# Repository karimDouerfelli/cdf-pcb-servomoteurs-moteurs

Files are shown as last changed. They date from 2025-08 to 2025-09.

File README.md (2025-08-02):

# 🛠️ PCB Servomoteurs & Moteurs – Coupe de France de Robotique 2026



Ce projet est un PCB dédié au pilotage de **moteurs** et **servomoteurs**, conçu pour la **Coupe de France de Robotique 2026**.

## ⚙️ Fonctionnalités principales

- Contrôle de servomoteurs via :
  - **UART**
  - **PWM**
- Carte en **4 couches** avec une **couche Power** divisée en 3 zones.

---

## 🧩 Schéma

### Schéma global :
Schéma global

### STM32 et ses compléments :
STM32

### Régulateurs :
Régulateurs

---

## 🧱 Empreintes

Empreinte 1  
Empreinte 2  
Empreinte 3  
Empreinte 4

---

## 🧵 Routage

### Placement des composants :
Placement

---

## 🧭 Couches PCB

- **GND Layer** :  
  GND

- **Top Layer (Rouge)** :  
  Top

- **Bottom Layer (Bleue)** :  
  Bottom

- **Power Layer** :  
  Power

---

## 📏 Dimensionnement des pistes

Nous avons utilisé la formule suivante pour calculer la largeur des pistes selon le courant attendu :

Formule  
Référence

---

## 🙏 Remerciements

Merci à **@CaptainJaja** pour son aide sur le projet ❤️  
CaptainJaja

---

## 💬 Retours bienvenus

N'hésitez pas à **ouvrir une issue** ou **créer une pull request** si vous avez des remarques ou des suggestions.

---

---

# 🛠️ PCB for Servomotors & Motors – French Robotics Cup 2026



This project is a PCB designed to control **motors** and especially **servomotors**, built for the **French Robotics Cup 2026**.

## ⚙️ Key Features

- Supports two control modes for servos:
  - **UART**
  - **PWM**
- Built on a **4-layer board** with a **Power layer** split into 3 zones.

---

## 🧩 Schematics

### Global schematic:
Schematic

### STM32 and peripherals:
STM32

### Voltage regulators:
Regulators

---

## 🧱 Footprints

Footprint 1  
Footprint 2  
Footprint 3  
Footprint 4

---

## 🧵 Routing

### Component placement:
Placement

---

## 🧭 PCB Layers

- **GND Layer**  
  GND

- **Top Layer (Red)**  
  Top

- **Bottom Layer (Blue)**  
  Bottom

- **Power Layer**  
  Power

---

## 📏 Trace Sizing

Trace widths were calculated using the following formula based on expected current:

Formula  
Reference

---

## 🙏 Acknowledgments

Big thanks to **@CaptainJaja** for contributions ❤️  
CaptainJaja

---

## 💬 Feedback

Feel free to **open an issue** or **submit a pull request** if you have ideas or improvements to suggest.

---

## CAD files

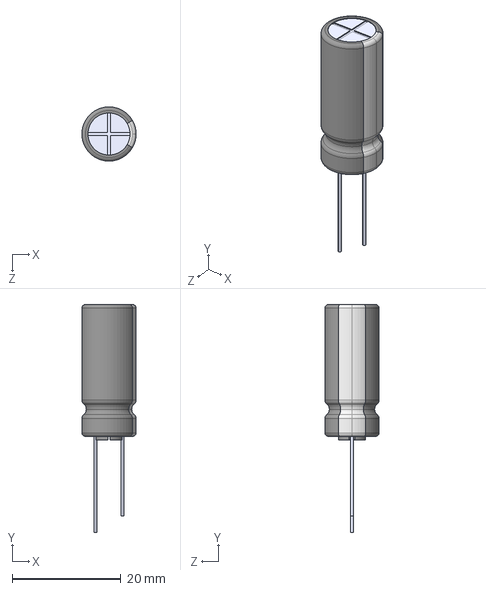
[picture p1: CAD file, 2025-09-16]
pcbservo-dc/EEUFS1K221LB/EEUFS1K221LB.step
10.0 x 42.0 x 9.99 mm

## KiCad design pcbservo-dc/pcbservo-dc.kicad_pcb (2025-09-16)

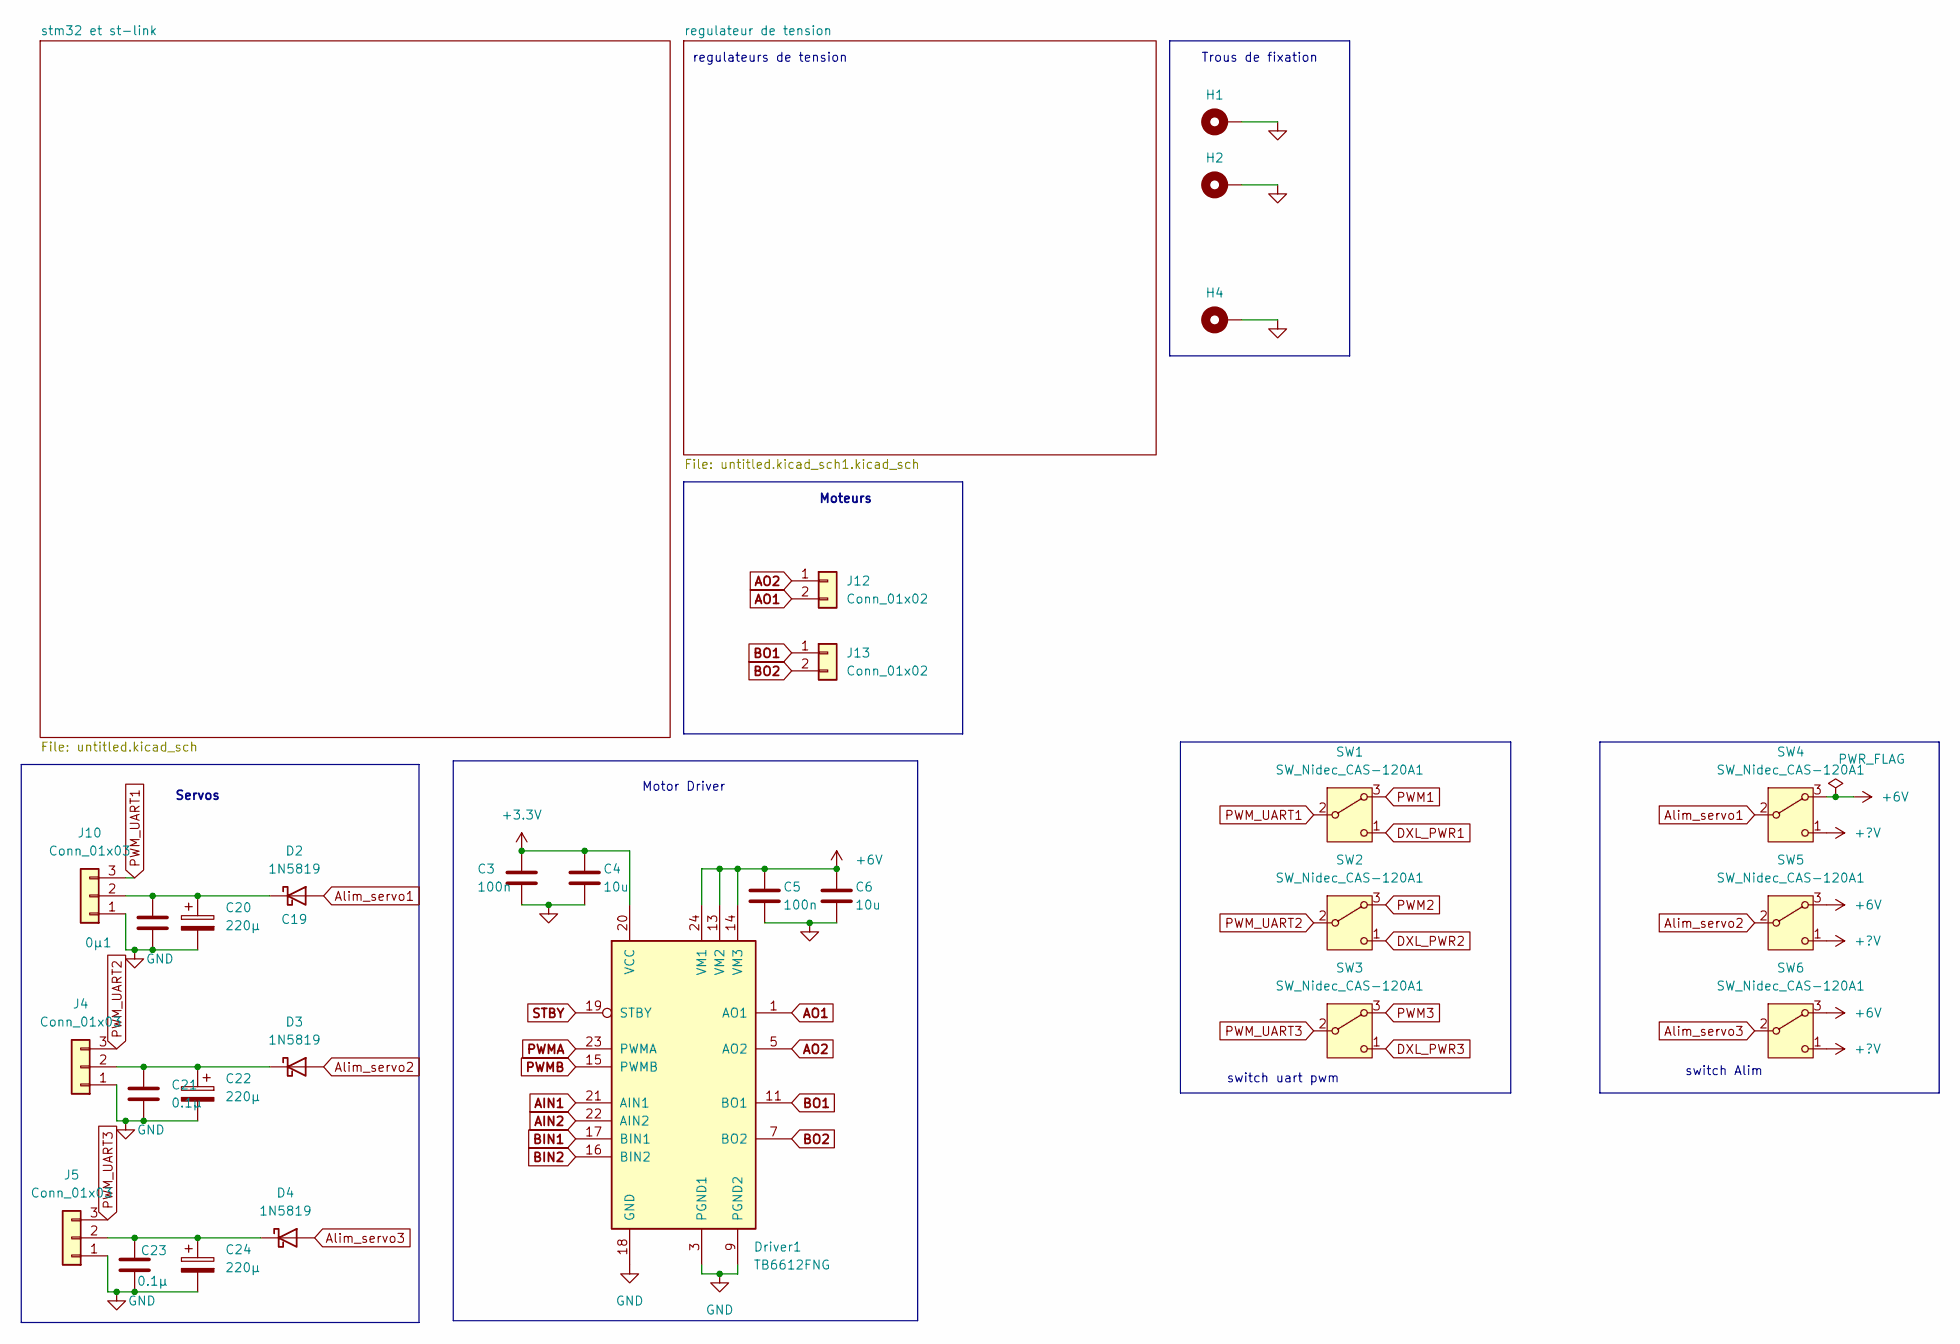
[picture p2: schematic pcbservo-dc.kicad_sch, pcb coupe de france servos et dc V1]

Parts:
C3, C5: 100n; C_0402_1005Metric
C4, C6: 10u; C_0805_2012Metric
C19: 0µ1; C_0805_2012Metric
C20, C22, C24: 220µ; CAPPRD500W60D1000H2500
C21, C23: 0.1µ; C_0805_2012Metric
D2, D3, D4: 1N5819; D_SOD-123
Driver1: TB6612FNG; SSOP-24_5.3x8.2mm_P0.65mm
H1, H2, H4: MountingHole_Pad; MountingHole_2.7mm_M2.5_Pad
J4, J5, J10: Conn_01x03; JST_EH_B3B-EH-A_1x03_P2.50mm_Vertical
J12, J13: Conn_01x02; JST_EH_B2B-EH-A_1x02_P2.50mm_Vertical
SW1, SW2, SW3, SW4, SW5, SW6: SW_Nidec_CAS-120A1; Nidec_Copal_CAS-120A

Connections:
+3.3V: C3.1, C4.1, Driver1.20 (VCC); also elsewhere on the board
+6V: C5.1, C6.1, Driver1.13 (VM2), Driver1.14 (VM3), Driver1.24 (VM1), SW4.3 (A), SW5.3 (A), SW6.3 (A); also elsewhere on the board
+?V: SW4.1 (C), SW5.1 (C), SW6.1 (C); also elsewhere on the board
AIN1: Driver1.21 (AIN1); also elsewhere on the board
AIN2: Driver1.22 (AIN2); also elsewhere on the board
AO1: Driver1.1 (AO1), Driver1.2 (AO1), J12.2
AO2: Driver1.5 (AO2), Driver1.6 (AO2), J12.1
Alim_servo1: D2.2 (A), SW4.2 (B)
Alim_servo2: D3.2 (A), SW5.2 (B)
Alim_servo3: D4.2 (A), SW6.2 (B)
BIN1: Driver1.17 (BIN1); also elsewhere on the board
BIN2: Driver1.16 (BIN2); also elsewhere on the board
BO1: Driver1.11 (BO1), Driver1.12 (BO1), J13.1
BO2: Driver1.7 (BO2), Driver1.8 (BO2), J13.2
DXL_PWR1: SW1.1 (C); also elsewhere on the board
DXL_PWR2: SW2.1 (C); also elsewhere on the board
DXL_PWR3: SW3.1 (C); also elsewhere on the board
GND: C3.2, C4.2, C5.2, C6.2, C19.2, C20.2, C21.2, C22.2, C23.2, C24.2, Driver1.3 (PGND1), Driver1.4 (PGND1), Driver1.9 (PGND2), Driver1.10 (PGND2), Driver1.18 (GND), H1.1, H2.1, H4.1, J4.1, J5.1, J10.1; also elsewhere on the board
unnamed: C19.1, C20.1, D2.1 (K), J10.2
unnamed: C21.1, C22.1, D3.1 (K), J4.2
unnamed: C23.1, C24.1, D4.1 (K), J5.2
PWM1: SW1.3 (A); also elsewhere on the board
PWM2: SW2.3 (A); also elsewhere on the board
PWM3: SW3.3 (A); also elsewhere on the board
PWMA: Driver1.23 (PWMA); also elsewhere on the board
PWMB: Driver1.15 (PWMB); also elsewhere on the board
PWM_UART1: J10.3, SW1.2 (B)
PWM_UART2: J4.3, SW2.2 (B)
PWM_UART3: J5.3, SW3.2 (B)
STBY: Driver1.19 (STBY); also elsewhere on the board

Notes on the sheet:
Trous de fixation
switch uart pwm
Servos
switch Alim
regulateurs de tension
Moteurs
Motor Driver

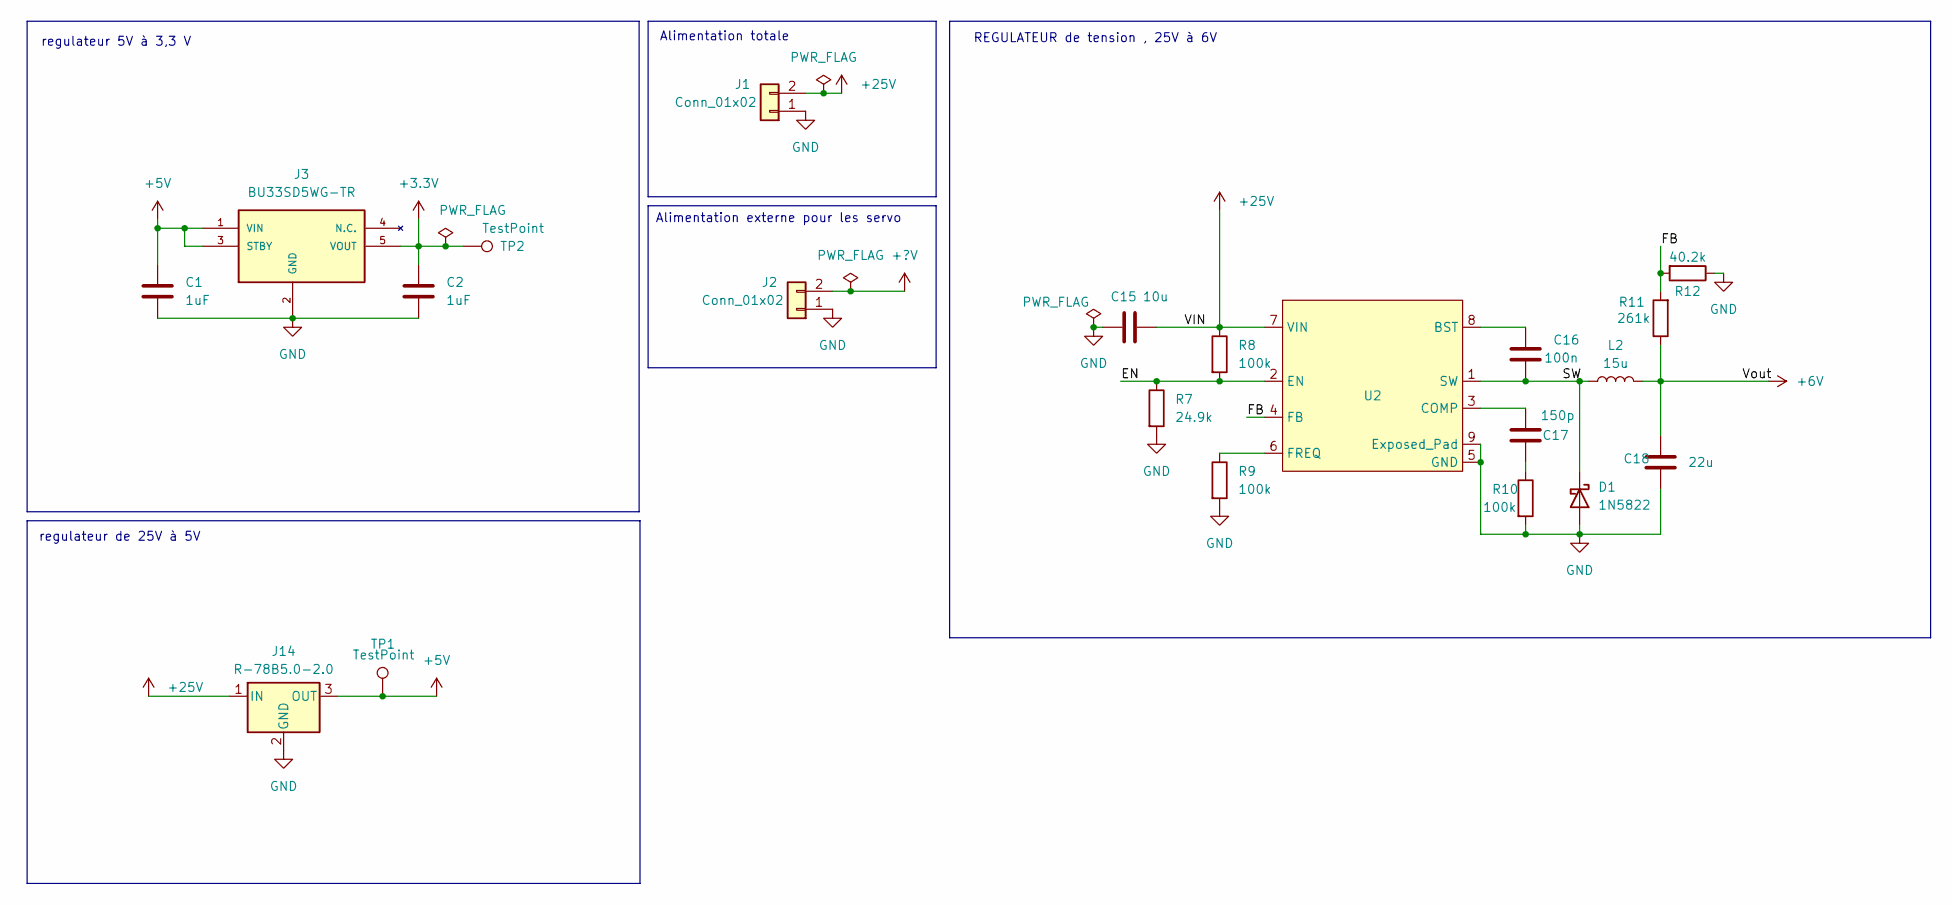
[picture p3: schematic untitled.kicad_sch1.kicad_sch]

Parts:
C1, C2: 1uF; C_0603_1608Metric_Pad1.08x0.95mm_HandSolder
C15: 10u; C_0603_1608Metric
C16: 100n; C_0603_1608Metric
C17: 150p; C_0603_1608Metric
C18: 22u; C_0805_2012Metric
D1: 1N5822; D_SMB
J1, J2: Conn_01x02; JST_EH_B2B-EH-A_1x02_P2.50mm_Vertical
J3: BU33SD5WG-TR; SOT-23-5; Mouser_Part_Number 755-BU33SD5WG-TR
J14: R-78B5.0-2.0; Converter_DCDC_RECOM_R-78B-2.0_THT
L2: 15u; L_12x12mm_H4.5mm
R7: 24.9k; R_0603_1608Metric
R8, R9, R10: 100k; R_0603_1608Metric
R11: 261k; R_0603_1608Metric
R12: 40.2k; R_0603_1608Metric
TP1, TP2: TestPoint; TestPoint_Pad_D1.0mm
U2: MP1584-SOICP8

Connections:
+3.3V: C2.1, J3.5 (VOUT), TP2.1; also elsewhere on the board
+5V: C1.1, J3.1 (VIN), J3.3 (STBY), J14.3 (OUT), TP1.1; also elsewhere on the board
+6V: C18.1, L2.2, R11.1; also elsewhere on the board
+25V: C15.1, J1.2, J14.1 (IN), R8.1, U2.7 (VIN)
+?V: J2.2; also elsewhere on the board
/regulateur de tension/EN: R7.1, R8.2, U2.2 (EN)
/regulateur de tension/FB: R11.2, R12.2, U2.4 (FB)
/regulateur de tension/SW: C16.2, D1.1 (K), L2.1, U2.1 (SW)
GND: C1.2, C2.2, C15.2, C18.2, D1.2 (A), J1.1, J2.1, J3.2 (GND), J14.2 (GND), R7.2, R9.2, R10.2, R12.1, U2.5 (GND), U2.9 (Exposed_Pad); also elsewhere on the board
unnamed: C17.2, R10.1
unnamed: C16.1, U2.8 (BST)
unnamed: C17.1, U2.3 (COMP)
unnamed: R9.1, U2.6 (FREQ)

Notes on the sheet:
regulateur 5V à 3,3 V
Alimentation externe pour les servo
REGULATEUR de tension , 25V à 6V
regulateur de 25V à 5V
Alimentation totale

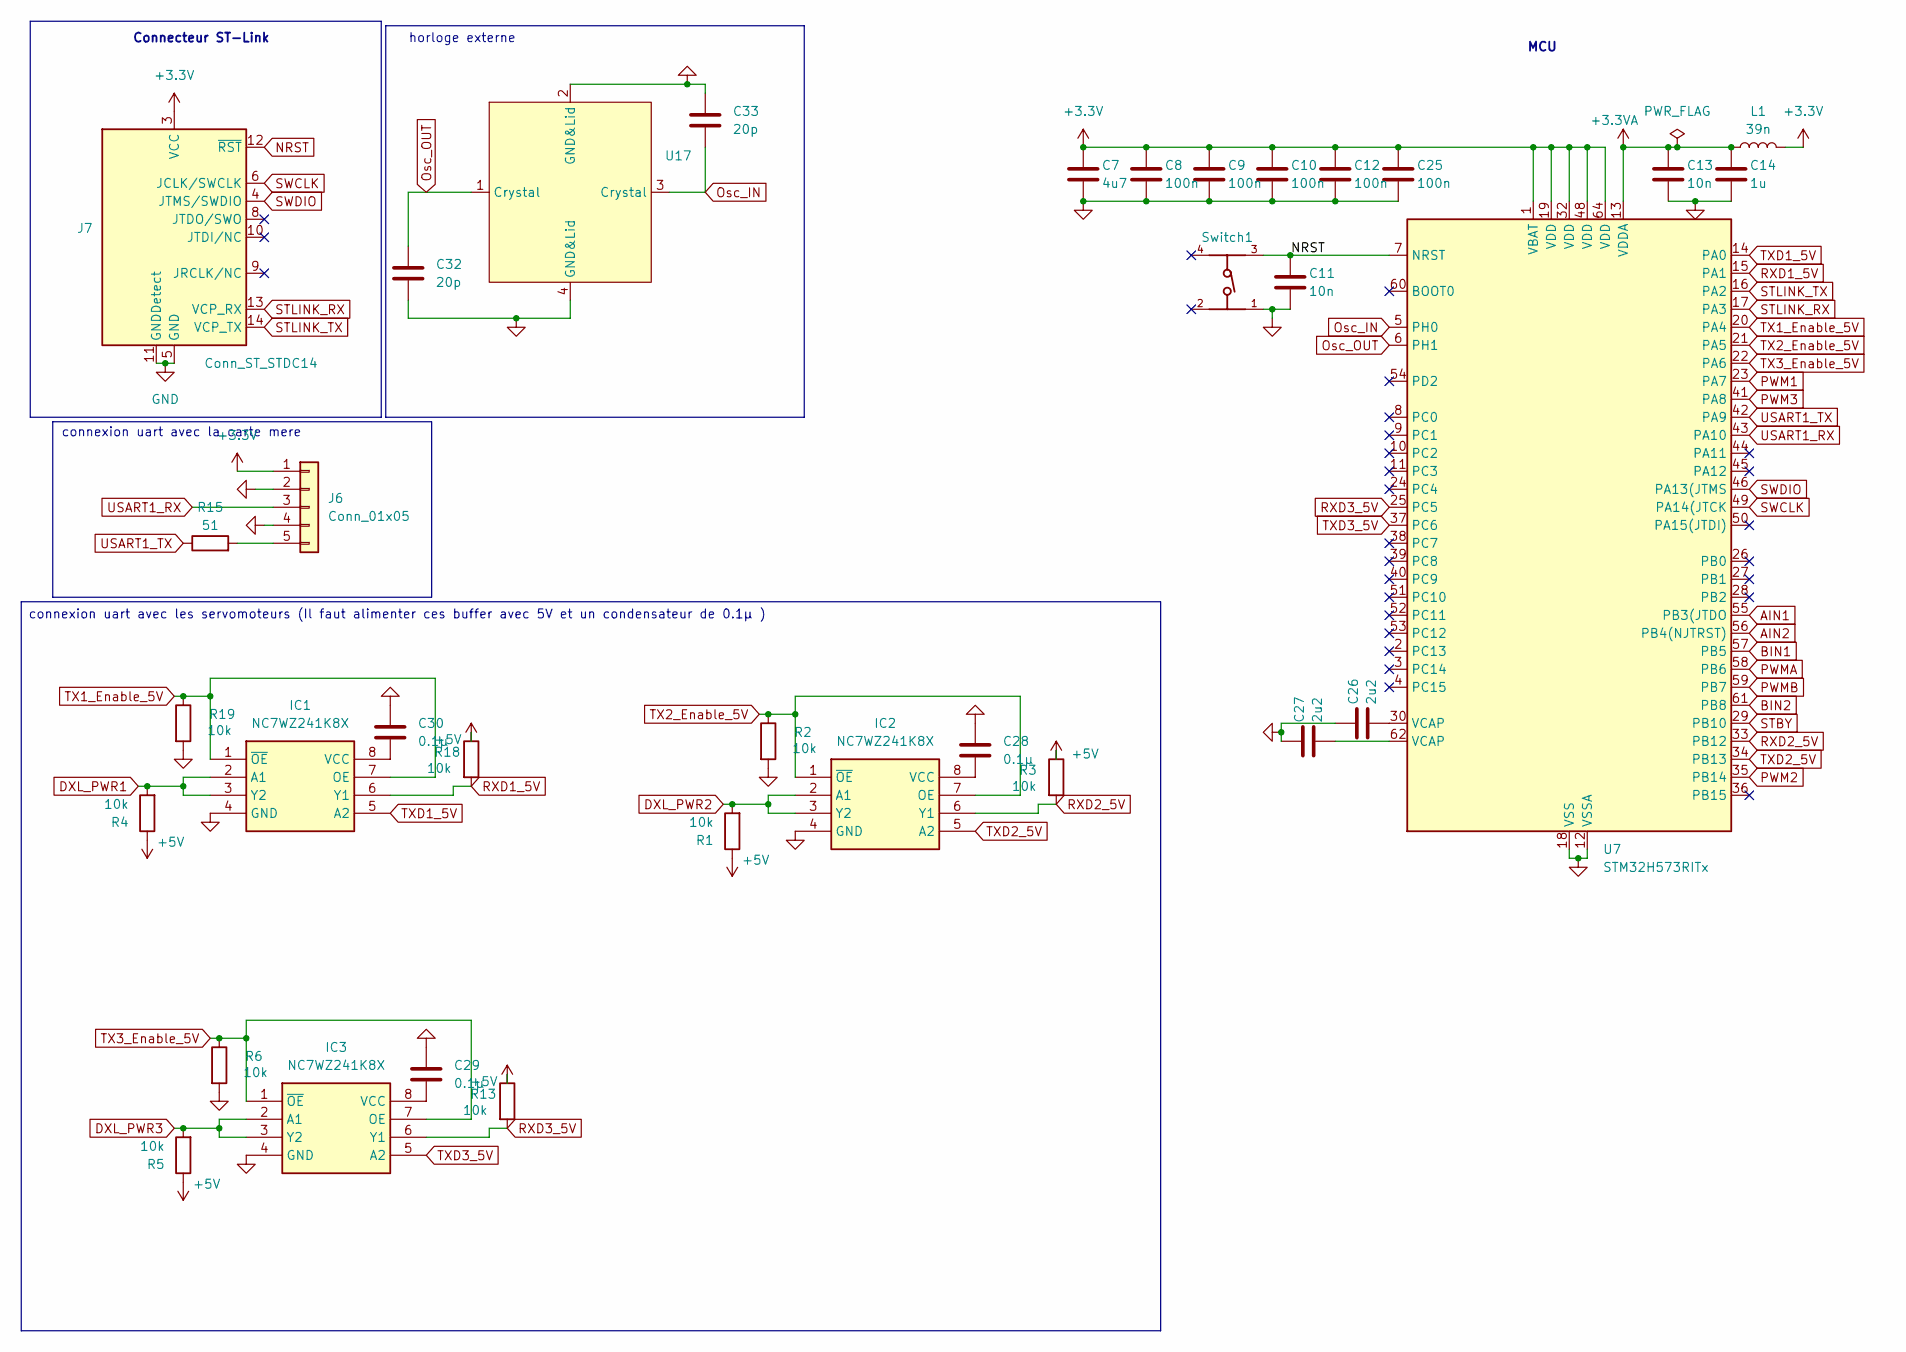
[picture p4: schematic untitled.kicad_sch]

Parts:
C7: 4u7; C_0805_2012Metric
C8, C9, C10, C12, C25: 100n; C_0402_1005Metric
C11, C13: 10n; C_0402_1005Metric
C14: 1u; C_0402_1005Metric
C26, C27: 2u2; C_0805_2012Metric
C28, C29, C30: 0.1µ; C_0603_1608Metric
C32, C33: 20p; C_0603_1608Metric
IC1, IC2, IC3: NC7WZ241K8X; UQFN8 1.6X1.6, 0.5P; Mouser Part Number 512-NC7WZ241K8X
J6: Conn_01x05; JST_EH_B5B-EH-A_1x05_P2.50mm_Vertical
J7: Conn_ST_STDC14; PinHeader_2x07_P1.27mm_Vertical_SMD
L1: 39n; L_0603_1608Metric
R1, R2, R3, R4, R5, R6, R13, R18, R19: 10k; R_0402_1005Metric
R15: 51; R_0402_1005Metric
Switch1: 430471025826; BOUTONPOUSSOIR; PART-NUMBER 430471025826
U7: STM32H573RITx; LQFP-64_10x10mm_P0.5mm
U17: Crystal_SMD_3225-4Pin_3.2x2.5mm

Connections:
+3.3V: C7.1, C8.1, C9.1, C10.1, C12.1, C25.1, J6.1, J7.3 (VCC), L1.2, U7.1 (VBAT), U7.19 (VDD), U7.32 (VDD), U7.48 (VDD), U7.64 (VDD); also elsewhere on the board
+3.3VA: C13.1, C14.1, L1.1, U7.13 (VDDA)
+5V: R1.1, R3.1, R4.1, R5.1, R13.1, R18.1; also elsewhere on the board
AIN1: U7.55 (PB3(JTDO); also elsewhere on the board
AIN2: U7.56 (PB4(NJTRST)); also elsewhere on the board
BIN1: U7.57 (PB5); also elsewhere on the board
BIN2: U7.61 (PB8); also elsewhere on the board
DXL_PWR1: IC1.2 (A1), IC1.3 (Y2), R4.2; also elsewhere on the board
DXL_PWR2: IC2.2 (A1), IC2.3 (Y2), R1.2; also elsewhere on the board
DXL_PWR3: IC3.2 (A1), IC3.3 (Y2), R5.2; also elsewhere on the board
GND: C7.2, C8.2, C9.2, C10.2, C11.2, C12.2, C13.2, C14.2, C25.2, C26.1, C27.1, C28.1, C29.1, C30.1, C32.2, C33.1, IC1.4 (GND), IC2.4 (GND), IC3.4 (GND), J6.2, J6.4, J7.5 (GND), J7.7 (GND), J7.11 (GNDDetect), R2.2, R6.2, R19.2, Switch1.1, U7.12 (VSSA), U7.18 (VSS), U7.31 (VSS), U7.47 (VSS), U7.63 (VSS), U17.2 (GND&Lid), U17.4 (GND&Lid); also elsewhere on the board
NRST: C11.1, J7.12 (~RST), Switch1.3, U7.7 (NRST)
unnamed: C26.2, U7.30 (VCAP)
unnamed: C27.2, U7.62 (VCAP)
unnamed: C30.2, IC1.8 (VCC)
unnamed: C28.2, IC2.8 (VCC)
unnamed: C29.2, IC3.8 (VCC)
unnamed: J6.5, R15.2
Osc_IN: C33.2, U7.5 (PH0), U17.3 (Crystal)
Osc_OUT: C32.1, U7.6 (PH1), U17.1 (Crystal)
PWM1: U7.23 (PA7); also elsewhere on the board
PWM2: U7.35 (PB14); also elsewhere on the board
PWM3: U7.41 (PA8); also elsewhere on the board
PWMA: U7.58 (PB6); also elsewhere on the board
PWMB: U7.59 (PB7); also elsewhere on the board
RXD1_5V: IC1.6 (Y1), R18.2, U7.15 (PA1)
RXD2_5V: IC2.6 (Y1), R3.2, U7.33 (PB12)
RXD3_5V: IC3.6 (Y1), R13.2, U7.25 (PC5)
STBY: U7.29 (PB10); also elsewhere on the board
STLINK_RX: J7.13 (VCP_RX), U7.17 (PA3)
STLINK_TX: J7.14 (VCP_TX), U7.16 (PA2)
SWCLK: J7.6 (JCLK/SWCLK), U7.49 (PA14(JTCK)
SWDIO: J7.4 (JTMS/SWDIO), U7.46 (PA13(JTMS)
TX1_Enable_5V: IC1.1 (~OE), IC1.7 (OE), R19.1, U7.20 (PA4)
TX2_Enable_5V: IC2.1 (~OE), IC2.7 (OE), R2.1, U7.21 (PA5)
TX3_Enable_5V: IC3.1 (~OE), IC3.7 (OE), R6.1, U7.22 (PA6)
TXD1_5V: IC1.5 (A2), U7.14 (PA0)
TXD2_5V: IC2.5 (A2), U7.34 (PB13)
TXD3_5V: IC3.5 (A2), U7.37 (PC6)
USART1_RX: J6.3, U7.43 (PA10)
USART1_TX: R15.1, U7.42 (PA9)

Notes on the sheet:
connexion uart avec la carte mere
horloge externe
Connecteur ST-Link
MCU
connexion uart avec les servomoteurs (Il faut alimenter ces buffer avec 5V et un condensateur de 0.1µ )

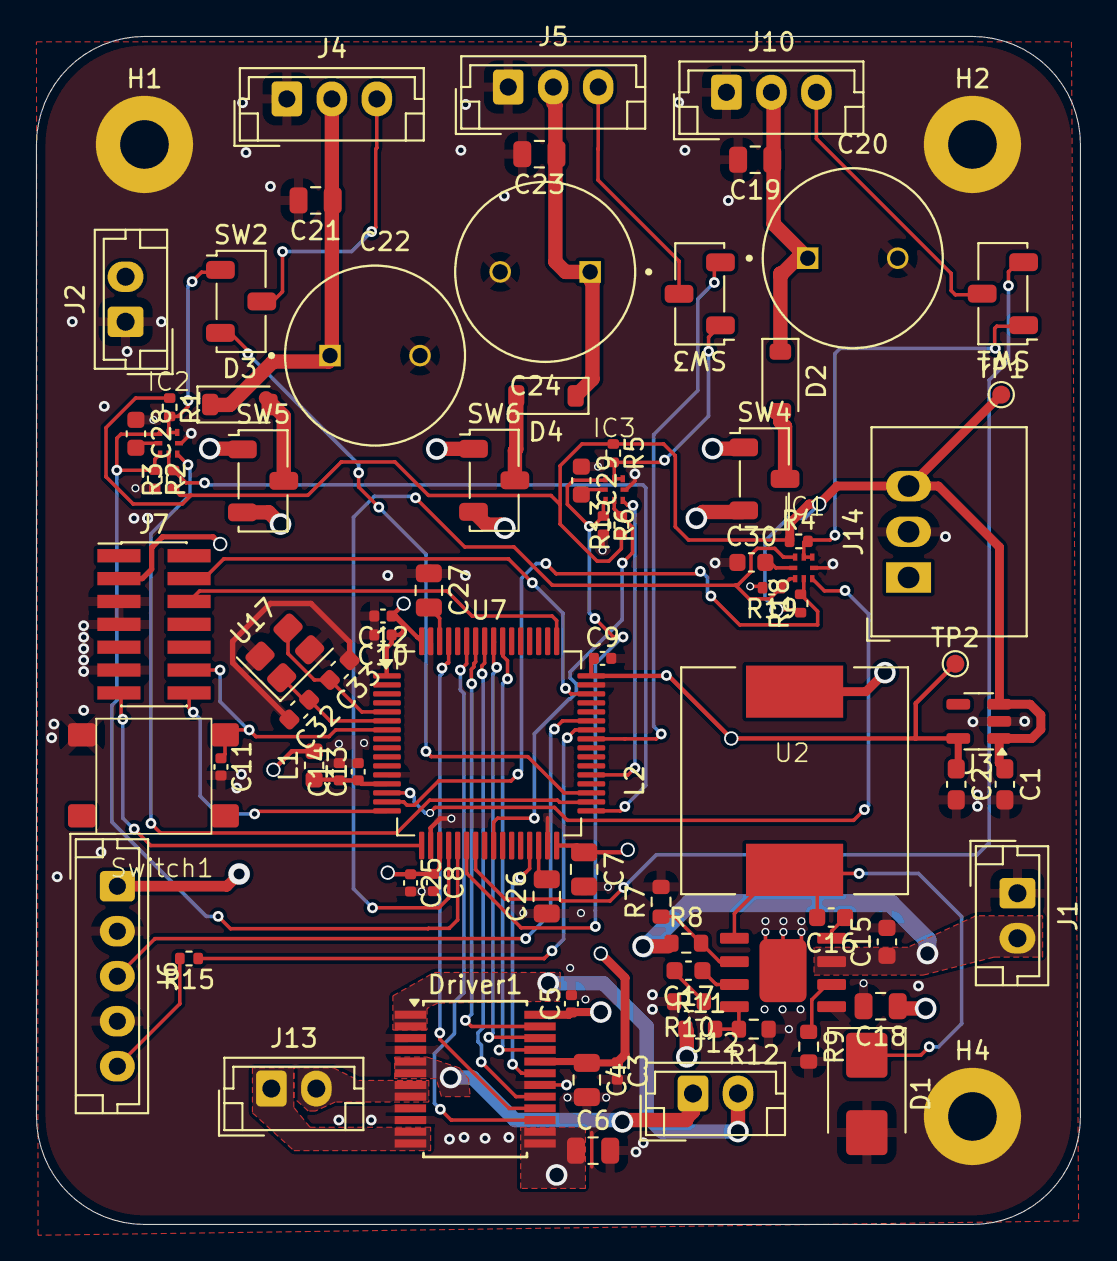
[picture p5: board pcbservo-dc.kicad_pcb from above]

Board: 4 copper layers, 58.0 x 66.0 mm, 84 parts (0 on the bottom side), 64 nets.

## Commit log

2025-09-11 uart a jour
    [pcbservo-dc.kicad_pcb, pcbservo-dc.kicad_sch, untitled.kicad_sch]
2025-09-11 modification des condensateur et des diode
    [pcbservo-dc.kicad_pcb, pcbservo-dc.kicad_sch]
2025-09-16 changement de quelques empreinte
    [EEUFS1K221LB.step, pcbservo-dc.kicad_pcb, pcbservo-dc.kicad_sch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]
